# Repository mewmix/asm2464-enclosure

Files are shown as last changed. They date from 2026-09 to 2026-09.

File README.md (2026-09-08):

# ASM2464PD USB4 / M.2 2230 Development Enclosure

Open development project for a compact ASM2464PD + M.2 2230 USB4 enclosure with firmware-development access built into the board and enclosure.

The immediate goals are:

1. reproduce and then improve the public Leaves232 ASM2464PD 2230 reference design;
2. expose the ASM2464PD firmware UART cleanly;
3. provide safe direct SPI access to the external firmware flash for backup, programming, and recovery;
4. co-design the PCB and enclosure rather than treating the enclosure as an afterthought;
5. use an agent-driven KiCad workflow modeled on the public i2cjak Astra + KiStack + T3CAD demonstration;
6. validate as much of the digital/recovery path as possible in simulation before Rev-A hardware.

## Agent-driven workflow

The public i2cjak demonstration describes an Astra-Medium hardware-design loop using **KiStack** and **T3CAD**, a T3Code fork. The exact private prompt/transcript is not published, so this repository documents a reproducible workflow built from the public tools and their documented capabilities.

Start with [`WORKFLOW.md`](WORKFLOW.md). Agents working in this repository must also read [`AGENTS.md`](AGENTS.md) and [`PROJECT_PLAN.md`](PROJECT_PLAN.md).

## Reference design

Electrical/mechanical reference:

- https://github.com/Leaves232/2230-USB4-SSD-Enclosure-Design

Controller datasheet pointer and extracted debug pins:

- [`reference/datasheets/ASM2464PD.md`](reference/datasheets/ASM2464PD.md)

Known reference-board geometry already extracted from the public Gerber/PnP data:

- controller PCB: **22.039834 x 33.680400 mm**;
- ASM2464PD center: **(13.667257, 14.870481) mm** from the PCB lower-left datum;
- USB-C center: **(11.069980, 29.187267) mm**;
- M.2 connector center: **(11.023879, 4.697654) mm**.

## Firmware-development interface

The service interface is deliberately narrow:

- ASM UART TX/RX;
- ASM reset;
- direct external SPI flash CS#/CLK/DI/DO;
- GND and target-voltage sense.

See [`DEBUG_ACCESS_AGENT_INSTRUCTIONS.md`](DEBUG_ACCESS_AGENT_INSTRUCTIONS.md).

## Mechanical model

The current CadQuery fit model lives at:

```text
mechanical/rev-a/model.py
```

Build it with:

```bash
python -m venv .venv
source .venv/bin/activate
pip install -r mechanical/rev-a/requirements.txt
python mechanical/rev-a/model.py
```

Generated STEP/STL files belong under `mechanical/rev-a/build/` and are intentionally ignored until geometry is mature enough to publish as release artifacts.

## Integrated CAD / simulation milestone

The shared board configuration now drives service access, physical SPI-isolation shunts, flash envelope clearance, and the virtual board. The imported upstream CPU executes project-owned reference firmware through UART/SPI MMIO. The CPU regression proves boot, deliberate flash bricking, programmer erase/program/full readback, and recovered boot.

```bash
python -m pip install -r simulation/requirements.txt
# Install SDCC using your platform package manager, then:
python scripts/validate_twin.py
```

See [validation outputs and limits](validation/README.md) and [the shared recovery design](hardware/rev-a/RECOVERY.md). STEP/STL and assembled/exploded PNGs are generated in `mechanical/rev-a/build/`. Geometry includes explicit provisional component envelopes, not a completed routed PCB.

**RTL remains blocked:** no Verilog/RTL sources exist at the inspected authoritative branch tip. `--require-rtl` makes that missing gate fail explicitly. No full dual-backend or fabrication-ready claim is made.

## Design gates before fabrication

Do not release Rev A for fabrication until:

- reference schematic/net tracing is complete;
- UART voltage is established;
- SPI flash voltage and exact part pinout are established;
- ASM SPI bus ownership under reset is proven or explicit isolation is designed;
- ERC/DRC pass with reviewed waivers only;
- USB4/PCIe routing rules are reviewed independently of generic DRC;
- debug connector and mating-cable keepouts are present in the mechanical model;
- ASM thermal path is modeled and does not depend on a printed-plastic lid for sustained operation;
- recovery simulation proves brick -> external flash recovery -> reboot -> UART confirmation.

## Source toolchain

- KiCad / `kicad-cli`
- KiStack: https://github.com/American-Embedded/KiStack
- T3CAD: https://github.com/i2cjak/T3CAD
- CadQuery
- Verilator + cocotb for digital board simulation
- ngspice/Xyce where circuit-level modeling is useful
- LiteNVMe as an optional open NVMe-host reference

## License / reference hygiene

Do not copy third-party source designs or datasheets into this repository unless their license permits redistribution. Keep source pointers, extracted facts, and our own derived design work separated and attributed.

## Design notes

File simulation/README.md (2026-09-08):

# Shared board simulation and imported ASM emulation

The working CPU/CAD milestone uses the **unchanged imported upstream CPU8051**, Memory, and HardwareState implementations at `acc935d351d49c66ab8d1026ee8cb4617609f782`. Generic SDCC-built mcs51 firmware runs from the upstream CODE-loading convention and drives actual UART/SPI MMIO. No CPU or controller RTL has been recreated.

`hardware/rev-a/board.json` couples the mechanical model to flash capacity/profile, boot offset and physical recovery-link states. The virtual programmer and CPU adapter use the same NOR instance. The model supports WEL/WIP, program/erase timing, NOR bit direction, status, ID, interruption and unsafe ownership detection. The firmware emits the expected boot banner; deliberate erasure prevents boot; external reprogramming and full readback restore it.

Run `python scripts/validate_twin.py` after installing SDCC and `simulation/requirements.txt`. See [validation instructions](../validation/README.md) for outputs, exact modeling limits, and the stricter `--require-rtl` gate.

The complete authoritative source tree contains no RTL files. Backend B and CPU/RTL differential comparison are **BLOCKED**, not skipped passes. The preserved two-backend requirements remain in [SIMULATION_WORK_INSTRUCTIONS.md](../SIMULATION_WORK_INSTRUCTIONS.md). Locate the existing RTL in the authoritative project before satisfying that gate.

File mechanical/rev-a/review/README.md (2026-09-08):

# CPU/CAD integration review artifacts

Generated from `model.py` and `hardware/rev-a/board.json` by `scripts/validate_twin.py`. STEP geometry and software renders are retained for this reviewed simulation milestone. `dimensions.json` and `cad-validation.json` record the shared board configuration hash.

The green/blue solids are board envelopes; service, shunt, chip and flash heights remain provisional. The metal insert has a lower locating flange and a modeled thermal pad path to the ASM envelope. This is not a completed PCB assembly or a fabrication release. See `validation/README.md` for unresolved gates.

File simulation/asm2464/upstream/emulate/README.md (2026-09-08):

# ASM2464PD Emulator

8051 CPU emulator for testing and analyzing the ASM2464PD firmware.

## Architecture

```
┌─────────────────────────────────────────────────────────────────┐
│                         Linux Host                               │
│                                                                  │
│  ┌──────────┐     USB      ┌──────────────────────────────────┐ │
│  │ USB App  │◄────────────►│         raw-gadget               │ │
│  │(usb.py)  │  (real USB)  │     (fake USB device)            │ │
│  └──────────┘              └──────────────┬───────────────────┘ │
│                                           │                      │
│                                      MMIO │ registers            │
│                                           ▼                      │
│                            ┌──────────────────────────────────┐ │
│                            │           Emulator               │ │
│                            │  ┌────────────────────────────┐  │ │
│                            │  │      fw.bin (8051)         │  │ │
│                            │  │   - USB interrupt handler  │  │ │
│                            │  │   - Vendor cmd processing  │  │ │
│                            │  │   - State machine          │  │ │
│                            │  └────────────────────────────┘  │ │
│                            │  ┌────────────────────────────┐  │ │
│                            │  │    Hardware Emulation      │  │ │
│                            │  │   - MMIO registers         │  │ │
│                            │  │   - DMA emulation          │  │ │
│                            │  │   - PCIe/NVMe stubs        │  │ │
│                            │  └────────────────────────────┘  │ │
│                            └──────────────────────────────────┘ │
└─────────────────────────────────────────────────────────────────┘
```

## USB Device Passthrough (raw-gadget)

The `usb_device.py` creates a fake USB device using Linux's raw-gadget kernel module.

**CRITICAL: The fake USB device is a passthrough, NOT a handler.**

**NOTE: NEVER implement USB request handling in Python.** The firmware (fw.bin) handles ALL USB requests including GET_DESCRIPTOR, SET_ADDRESS, SET_CONFIGURATION, and vendor commands. The emulator only sets MMIO registers to inject requests; the 8051 firmware code processes them. If USB enumeration doesn't work, fix the MMIO register configuration or investigate firmware flow - do NOT add Python code to handle USB requests directly.

When the host sends USB control messages:

**All USB Control Transfers** (standard and vendor):
1. **raw-gadget receives** the USB setup packet
2. **usb_device.py injects** the request into emulator MMIO registers
3. **Firmware processes** the request via USB interrupt handler (0x0E33)
4. **Firmware writes** response to appropriate registers/buffers
5. **usb_device.py reads** the response from emulator
6. **raw-gadget sends** the response back to the host

### Control Transfer Flow

```
Host                    raw-gadget/usb_device.py              Emulator (fw.bin)
  │                              │                                   │
  │──USB control transfer───────►│                                   │
  │                              │──inject to MMIO registers────────►│
  │                              │  (0x9E00-0x9E07 = setup packet)   │
  │                              │──trigger USB interrupt───────────►│
  │                              │                                   │
  │                              │                    [firmware runs]│
  │                              │                    [reads MMIO]   │
  │                              │                    [processes req]│
  │                              │                    [writes resp]  │
  │                              │                                   │
  │                              │◄──read response from XDATA/MMIO───│
  │◄─────response data──────────│                                   │
```

### USB Descriptor Handling

**Descriptors are handled entirely by firmware through MMIO:**

1. Firmware receives GET_DESCRIPTOR request via setup packet at 0x9E00-0x9E07
2. Firmware reads descriptor data from flash ROM mirror (XDATA 0xE4xx → Code ROM)
   - The hardware maps XDATA reads at 0xE400-0xE500 to code ROM with offset 0xDDFC
   - Formula: `code_addr = xdata_addr - 0xDDFC`
3. Firmware writes response to EP0 FIFO (0xC001)
4. Firmware triggers DMA (writes 0x04 to 0x9092)
5. Hardware DMA copies FIFO data to USB buffer at 0x8000
6. usb_device.py reads response from 0x8000

**IMPORTANT:** The emulator does NOT hardcode descriptor addresses. The `_flash_rom_mirror_read`
callback provides the MMIO hardware behavior - it maps XDATA reads to code ROM. The firmware
determines which addresses to read based on its own descriptor tables.

### Key MMIO Registers

| Register | Purpose |
|---|---|
| 0xC802 | Interrupt status (bit 0 = USB interrupt pending) |
| 0x9000 | USB connection status |
| 0x9101 | USB interrupt flags (bit 5 = vendor command path) |
| 0x9E00-0x9E07 | USB setup packet (8 bytes) |
| 0x910D-0x9112 | CDB data for SCSI/vendor commands |
| 0x90E3 | USB endpoint status |
| 0x8000+  | USB data buffer (for responses) |

### USB Setup Packet Registers (0x9E00-0x9E07)

The firmware handles ALL USB control transfers via these registers:

| Offset | Register | USB Setup Field |
|---|---|---|
| 0x9E00 | bmRequestType | Request type (direction, type, recipient) |
| 0x9E01 | bRequest | Request code (e.g., 0x06 = GET_DESCRIPTOR) |
| 0x9E02 | wValue low | Value field low byte |
| 0x9E03 | wValue high | Value field high byte |
| 0x9E04 | wIndex low | Index field low byte |
| 0x9E05 | wIndex high | Index field high byte |
| 0x9E06 | wLength low | Data length low byte |
| 0x9E07 | wLength high | Data length high byte |

The firmware processes standard USB requests (GET_DESCRIPTOR, SET_ADDRESS, etc.)
as well as vendor-specific requests (E4/E5) through the USB interrupt handler at 0x0E33.

### Vendor Commands (E4/E5)

Vendor commands follow the same passthrough model:

1. Host sends UAS command packet on EP4 OUT
2. raw-gadget receives bulk transfer
3. usb_device.py injects CDB into registers 0x910D+
4. Firmware processes via vendor handler (0x5333 → 0x4583)
5. For E4 reads: firmware DMAs data to 0x8000
6. usb_device.py reads response buffer
7. raw-gadget sends data back on EP1 IN

## Files

- `emu.py` - Main Emulator class
- `cpu.py` - 8051 CPU emulation
- `memory.py` - Memory system (code, xdata, idata, sfr)
- `hardware.py` - MMIO register emulation
- `raw_gadget.py` - Python wrapper for raw-gadget kernel module
- `usb_device.py` - USB device passthrough (connects raw-gadget to emulator)

## Running Tests

```bash
# Test firmware handling (without real USB)
pytest test/test_emulator.py -v

# Test with real USB device (requires root, raw-gadget module)
sudo modprobe dummy_hcd raw_gadget
sudo python emulate/emu.py --usb-device fw.bin
```

## Requirements for USB Device Mode

1. Linux kernel with dummy_hcd and raw_gadget modules
2. Root privileges
3. No conflicting gadget drivers

```bash
# Load required modules
sudo modprobe dummy_hcd
sudo modprobe raw_gadget

# Verify
ls /dev/raw-gadget
ls /sys/class/udc/
```

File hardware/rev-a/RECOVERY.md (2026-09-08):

# Proposed Rev-A recovery architecture

`board.json` is the shared digital/mechanical contract. The current design selects **four removable shunts**, one each in CS#, CLK, MOSI, and MISO. The programmer connects to the flash side. Reset is held during shunt removal and replacement. All four links must be open before programmer attachment. VREF is sense-only; the programmer must not power the target through it.

The CAD includes separate service-connector and isolation-shunt envelopes and top service openings. These are **design envelopes**, not verified manufacturer models. The isolated flash needs a defined idle CS# level in the eventual schematic; resistor value, rail voltage, connector part and signal integrity remain electrical gates. No completed Rev-A schematic/routed PCB is claimed by this fit-model milestone.

Simulation ownership is derived from each physical link state. Reset alone never grants ownership. A deliberately shorted link produces a contention error. A controller that refuses to tri-state cannot drive through removed shunts.

Procedure: hold reset → remove all four shunts → attach programmer to flash-side connector → read JEDEC → save complete backup → erase/program → full readback and SHA-256 verification → detach programmer → replace all four shunts → release reset → capture UART boot.

Controller SPI signal names in the previous reference notes contain conflicting DI/DO direction descriptions. This model therefore uses functional MOSI/MISO names and does **not** assign new ASM ball-to-flash wiring. Resolve the actual net directions from the reference schematic before authoring the board. The CAD and simulator share ownership architecture, not an unverified netlist.

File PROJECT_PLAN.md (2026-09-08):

# USB4 2230 ASM2464PD Development Enclosure — Repo Plan

## Project goal

Build our own compact ASM2464PD + M.2 2230 USB4 enclosure that is also usable as a firmware-development unit.

The development scope is deliberately narrow:

1. **Write/read the ASM2464PD external firmware flash directly over SPI.**
2. **Debug/controller-console access over UART.**

Do not add JTAG, SWD, I2C, general GPIO, or unrelated service interfaces unless a later requirement explicitly needs them.

## Mandatory coupled simulation deliverable

Rev-A consists of the KiCad board, CadQuery mechanical/thermal enclosure, imported/pinned existing ASM CPU-emulator + Verilog backends, and a common board model proving firmware boot, UART, external SPI programming, deliberate bricking, and recovery. Check changes across all four layers. Follow [`SIMULATION_WORK_INSTRUCTIONS.md`](SIMULATION_WORK_INSTRUCTIONS.md), sections 13–25, in full.

The first simulation milestone is deterministic project-owned reference firmware boot and brick/recovery against both imported backends using the same board and fault corpus. Both must ultimately pass; unsupported execution is a recorded blocker. More realistic firmware follows without changing the board underneath it. Physical validation below remains required.

## Primary references

### ASM2464PD datasheet

See [`reference/datasheets/ASM2464PD.md`](reference/datasheets/ASM2464PD.md).

Relevant controller pins currently extracted from the datasheet:

- `UART_TX` — B21
- `UART_RX` — A21
- `SPI_CS#` — A2
- `SPI_DO` — A3
- `SPI_DI` — A4
- `SPI_CLK` — A5
- `RST#` — H1

### Reference PCB

Use Leaves232's `2230-USB4-SSD-Enclosure-Design` as the electrical/mechanical reference baseline. Keep imported/reference material read-only and place our changes under our own `hardware/` and `mechanical/` trees.

Known reference-board facts already extracted:

- controller PCB: 22.039834 x 33.680400 mm;
- controller: ASM2464PD;
- external serial flash: U31, `ZD25WQ16CEIGR`;
- M.2 2230 SSD extends beyond the controller PCB;
- USB-C receptacle is at the controller-board end.

## Repository structure target

```text
reference/
  datasheets/
    ASM2464PD.md
  leaves232-b2/
    README.md
    debug-net-map.md
hardware/
  rev-a/
    schematic/
    pcb/
    fab/
mechanical/
  rev-a/
    model.py
    build/
validation/
  electrical/
  mechanical/
docs/
  uart-debug.md
  flash-programming.md
README.md
PROJECT_PLAN.md
```

## Rev A debug connector

Prefer a compact keyed 2x5, 1.27 mm header or an equivalent pogo/Tag-Connect footprint if enclosure constraints make a permanent header undesirable.

Provisional signals:

| Pin | Signal | Direction/role |
|---:|---|---|
| 1 | GND | reference |
| 2 | VREF_SENSE | target logic/flash-rail sense only |
| 3 | ASM_UART_TX | target -> adapter |
| 4 | ASM_UART_RX | adapter -> target |
| 5 | ASM_RST_N | controller reset control |
| 6 | ASM_SPI_CS_N | flash programming |
| 7 | ASM_SPI_CLK | flash programming |
| 8 | ASM_SPI_DI | programmer MOSI -> flash path |
| 9 | ASM_SPI_DO | flash -> programmer MISO path |
| 10 | GND | reference |

Do **not** provide debugger/programmer power to the board through `VREF_SENSE`.

## Electrical architecture

### UART

Route the dedicated ASM2464PD UART pins directly to the development connector through optional small series resistors/0-ohm links for bring-up flexibility.

Requirements:

- determine and document the UART I/O voltage before attaching an adapter;
- label TX/RX from the **target's perspective**;
- keep the traces short and away from USB4 high-speed pairs;
- provide a solid ground next to the UART pins.

The repo must not hard-code a UART baud rate unless it is confirmed from firmware/runtime evidence. Datasheet pin identity and runtime serial configuration are separate facts.

### Direct SPI flash programming

U31 is the firmware flash. The direct-programming path must reach the **flash-side** SPI nets:

- CS#
- CLK
- DI/MOSI
- DO/MISO
- target ground
- target flash-rail reference/sense

The normal operating path remains ASM2464PD <-> U31.

The key design problem is **bus ownership**. An external programmer must never fight the ASM2464PD for the flash bus.

Implementation order:

1. Prove whether asserting `ASM_RST_N` causes the controller to release/tri-state all four SPI signals.
2. If yes, document `RST# asserted + board powered normally` as the preferred in-circuit programming state.
3. If no, add a deliberate hardware isolation mechanism in Rev A. Prefer a low-risk topology that does not compromise normal flash timing/signal integrity. Do not rely on software cooperation from potentially corrupted firmware.

Avoid casually inserting analog switches or long stubs into the production flash bus. If active isolation is needed, it requires signal-integrity review and validation at the actual flash clock rate.

## Bring-up workflow target

### UART firmware debug

1. Power the enclosure normally over USB-C.
2. Connect GND and `VREF_SENSE` first.
3. Confirm logic voltage.
4. Connect adapter RX to `ASM_UART_TX` and adapter TX to `ASM_UART_RX`.
5. Capture boot/debug output.
6. Determine baud/framing from verified firmware/runtime evidence and record it in `docs/uart-debug.md`.

### Direct flash write/recovery

1. Power the target using the documented target-power method.
2. Assert the verified controller-reset/isolation state.
3. Confirm the ASM is not driving CS#/CLK/DI/DO.
4. Connect programmer GND and sense the target flash voltage.
5. Read flash JEDEC ID.
6. Read and save a complete backup before any write/erase.
7. Program only a verified image with size/range checks.
8. Read back and verify the programmed contents.
9. Disconnect programmer.
10. Release reset/isolation and boot normally.

## Mechanical requirements

The enclosure model must include:

- the real debug-connector body;
- mating-plug/cable keepout;
- service aperture or removable cover;
- no collision with the USB-C cable;
- no interference with the M.2 2230 SSD;
- no loss of thermal contact to the ASM2464PD heat spreader/pad.

The header must be usable with the device fully assembled.

## Validation gates

Rev A is not complete until all of these are demonstrated:

- UART TX/RX continuity from ASM balls to connector;
- UART voltage confirmed;
- SPI CS#/CLK/DI/DO continuity from U31/ASM bus to connector;
- flash voltage confirmed;
- reset/isolation behavior proven with a scope or logic analyzer;
- external programmer can read JEDEC ID without contention;
- full flash can be backed up and verified;
- a test image can be written/read-back verified on sacrificial hardware;
- UART can capture controller boot/debug output;
- enclosure/cable/header clearances pass mechanically;
- ASM thermal-interface geometry remains intact.

## Deliverable sequence

1. `reference: add ASM2464PD datasheet facts and source pointer`
2. `reference: trace B2 UART and external-flash nets`
3. `hardware: add Rev A UART + direct-SPI service connector`
4. `hardware: add reset/isolation strategy for safe flash programming`
5. `mechanical: model debug connector and service aperture`
6. `docs: add UART debug and flash recovery procedures`
7. `validation: prove bus release, flash read/write, UART capture, and enclosure clearance`

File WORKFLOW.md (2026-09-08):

# Agent-Driven Hardware Workflow

## What this reproduces from the public demo

The public i2cjak post says Astra-Medium produced a Bluetooth hardware design in roughly 30 minutes using **KiStack** and **T3CAD**, i2cjak's fork of T3Code. Public T3CAD documentation describes an agent-driven workspace combining coding-agent conversations with KiCad schematic, PCB, Gerber, BOM, footprint, symbol, 3D, and analysis views. KiStack is a human-written set of agent skills for KiCad schematic work, PCB review, parts/BOM decisions, exports, and Gerber review.

The original private agent transcript is not public. This document therefore defines our reproducible equivalent for the ASM2464PD enclosure.

## 0. Install the toolchain

### KiCad

Install a current KiCad release and ensure `kicad-cli` is on PATH. T3CAD requires `kicad-cli` for BOM, footprint, symbol, and 3D previews. Python 3 is required for Gerber previews.

Verify:

```bash
kicad-cli version
python3 --version
```

### KiStack

Install the public KiStack skills:

```bash
npx skills add American-Embedded/kistack
```

Source: https://github.com/American-Embedded/KiStack

### T3CAD

T3CAD currently runs from source. Install Vite+ first.

macOS/Linux:

```bash
curl -fsSL https://vite.plus | bash
```

Windows PowerShell:

```powershell
irm https://vite.plus/ps1 | iex
```

Then:

```bash
git clone https://github.com/i2cjak/T3CAD.git
cd T3CAD
vp i
vp run dev
```

Open the pairing URL printed by the development server. `vp run dev --share` can expose the isolated development environment over a Tailnet.

### Mechanical CAD

The tweet's stack is electronics-focused. This repository adds CadQuery for deterministic, version-controlled enclosure geometry:

```bash
pip install -r mechanical/rev-a/requirements.txt
```

## 1. Start the agent in repository mode

The agent must work against this repository, not a blank chat.

First read, in order:

1. `AGENTS.md`
2. `PROJECT_PLAN.md`
3. `DEBUG_ACCESS_AGENT_INSTRUCTIONS.md`
4. `reference/datasheets/ASM2464PD.md`
5. the Leaves232 reference repo and its schematic/PCB/fabrication files

The first response should summarize hard facts, assumptions, unresolved electrical questions, and the next smallest design pass. Do not immediately generate a finished PCB.

## 2. Ingest the reference design as evidence

Use the Leaves232 project as a read-only baseline:

- schematic and PCB source;
- Gerbers and drill files;
- BOM;
- pick-and-place;
- board outline;
- component placement;
- power tree;
- USB-C / ASM2464PD / M.2 topology;
- external flash connection;
- thermal constraints.

Create project-owned evidence artifacts rather than modifying the reference:

```text
reference/leaves232-b2/
  debug-net-map.md
  debug-net-map.json
  power-tree.md
  placement-datums.json
  open-questions.md
```

Every assertion should be classified as one of:

- `DATASHEET`
- `REFERENCE_SCHEMATIC`
- `REFERENCE_PCB`
- `FAB_OUTPUT`
- `MEASURED`
- `INFERRED`
- `ASSUMED`

## 3. Freeze the design contract before placement

Create/maintain a short design contract containing:

- exact board outline target;
- M.2 2230 mechanical datum;
- USB-C receptacle and shell datum;
- ASM2464PD footprint and thermal region;
- external SPI flash part/footprint;
- power requirements;
- UART/SPI recovery connector choice;
- enclosure/service-access constraints;
- manufacturing stackup and routing constraints.

Do not let the agent silently change these during routing.

## 4. Schematic pass

Use the agent + KiStack to reconstruct/author the KiCad schematic in small subsystems:

1. USB-C input and protection;
2. ASM2464PD core/power/clock/reset;
3. external SPI firmware flash;
4. UART + SPI recovery/service connector;
5. PCIe/M.2 interface;
6. power regulators and sequencing;
7. status LED and remaining support circuits.

After each subsystem:

```bash
kicad-cli sch erc <project>.kicad_sch
```

Review warnings deliberately. Do not suppress ERC failures merely to get a green build.

## 5. Footprint lock

Before serious PCB placement, lock footprints whose physical geometry affects the enclosure:

- USB-C receptacle;
- ASM2464PD;
- M.2 connector;
- SPI flash;
- large capacitors/inductors;
- service/debug connector;
- mounting/retention hardware.

Confirm courtyard, body height, pin-1 orientation, and 3D model where available.

This is a critical correction to a pure "one-shot" flow: an electrically valid connector that cannot be assembled or accessed is still a failed design.

## 6. PCB placement loop in T3CAD

Use T3CAD as the steering surface while the agent edits the KiCad project.

Recommended loop:

1. agent proposes one placement/routing pass;
2. inspect schematic/PCB/3D in T3CAD;
3. compare against the frozen mechanical datums;
4. run DRC;
5. inspect high-speed routes manually;
6. commit a small checkpoint;
7. continue.

Prioritize placement in this order:

1. board outline / USB-C / M.2 mechanical endpoints;
2. ASM2464PD;
3. clocks and high-speed support parts;
4. power conversion/decoupling;
5. SPI flash close to ASM;
6. recovery connector where it remains accessible in the final enclosure;
7. remaining low-speed support circuitry.

## 7. High-speed routing rules

Do not treat generic autorouting or a clean DRC as proof of USB4/PCIe correctness.

The agent must explicitly track:

- stackup and target differential impedance;
- pair geometry and reference plane continuity;
- intra-pair and inter-pair skew budgets where applicable;
- via count and stubs;
- return-path discontinuities;
- connector escape geometry;
- separation from switch-node/power noise;
- avoidance of unnecessary debug/test stubs on high-speed nets.

Reference-design topology is evidence, not permission to copy blindly.

## 8. Firmware-development access

Implement only what we need:

- `ASM_UART_TX`
- `ASM_UART_RX`
- `ASM_RST_N`
- `ASM_SPI_CS_N`
- `ASM_SPI_CLK`
- `ASM_SPI_DI`
- `ASM_SPI_DO`
- GND
- target-voltage sense

Direct flash programming must be safe even when firmware is corrupt. Bus ownership is a hardware requirement. Prove that reset tri-states the ASM SPI pins, or provide explicit isolation.

See `DEBUG_ACCESS_AGENT_INSTRUCTIONS.md`.

## 9. Mechanical co-design

After the first stable placement pass, regenerate the CadQuery enclosure from actual PCB datums rather than hand-entered estimates.

Mechanical iteration must check:

- board outline;
- USB-C opening and plug insertion envelope;
- SSD envelope;
- component maximum-Z envelopes;
- debug connector body and mating cable;
- thermal pad/spreader compression;
- screw/clip locations;
- assembly sequence;
- service access without opening the enclosure.

Run PCB and enclosure development in parallel from this point onward.

## 10. Simulation before fabrication

The four coupled Rev-A artifacts and mandatory simulation requirements are defined in [`SIMULATION_WORK_INSTRUCTIONS.md`](SIMULATION_WORK_INSTRUCTIONS.md), sections 13–25. Read and follow that contract in full. Reuse pinned imports of the existing CPU emulator and Verilog model from `mewmix/asm2464pd-opal`; do not build replacement ASM implementations.

The first milestone is deterministic generic firmware boot and deliberate brick/recovery using both execution backends on the same virtual board. Both must ultimately pass. Unsupported capabilities are recorded blockers, never passing mocks. The flash, UART, reset, programmer ownership, fault corpus, and synthetic PCIe/NVMe endpoint belong to the common board model. Recovery must represent the circuit actually selected for the PCB.

Keep existing circuit-level/electrical checks and physical validation gates. LiteNVMe remains an optional secondary oracle subordinate to stock ASM evidence.

## 11. Automated validation loop

Each meaningful design pass should run as much of this as applies:

```text
schematic ERC
PCB DRC
BOM generation/review
footprint review
Gerber export/review
pick-and-place export/review
3D inspection
mechanical model build
clearance/interference checks
simulation regression
```

The point of KiStack/T3CAD is not "AI drew a PCB." The useful loop is **agent edit -> deterministic validation -> visual inspection -> evidence update -> next agent edit**.

## 12. Pre-fabrication signoff

Before ordering Rev A, require all of the following:

- schematic reviewed subsystem-by-subsystem;
- DRC/ERC clean or every waiver documented;
- high-speed routing independently reviewed;
- pin-1/orientation review complete;
- BOM availability checked;
- flash/UART voltage assumptions resolved;
- safe external-flash ownership strategy resolved;
- fabrication outputs reviewed, not merely generated;
- enclosure interference check passes;
- thermal strategy defined;
- brick/recovery simulation passes;
- manufacturing notes and bring-up procedure committed.

## Physical fabrication, assembly, and feedback

On physical Rev A:

1. inspect bare/assembled board;
2. validate rails before fitting the ASM/SSD where practical;
3. measure reset and flash-bus behavior;
4. back up factory/reference flash before writing;
5. validate UART electrically;
6. perform controlled SPI recovery test on sacrificial/rework-safe hardware;
7. exercise USB4/NVMe and thermal behavior;
8. feed measured dimensions, temperatures, signal captures, and failures back into the repo as `MEASURED` evidence.

The physical board is the final oracle for the next revision.

## Canonical agent prompt

Use this as the starting instruction for an Astra/Work/Codex-style agent:

> The Rev-A deliverable consists of FOUR coupled artifacts: (1) KiCad ASM2464PD development board; (2) CadQuery mechanical/thermal enclosure; (3) imported/pinned ASM2464 CPU-emulator + Verilog simulation backend; (4) board-level simulation proving firmware boot, UART debugging, external SPI programming, deliberate bricking, and recovery. Check changes in each layer against the other layers. Reuse the existing ASM emulator/RTL; never replace it with a toy ASM behavioral stub. Work directly in `mewmix/asm2464-enclosure`. Read `AGENTS.md`, `WORKFLOW.md`, `PROJECT_PLAN.md`, `DEBUG_ACCESS_AGENT_INSTRUCTIONS.md`, `SIMULATION_WORK_INSTRUCTIONS.md` (all mandatory sections 13–25), and the ASM2464PD datasheet notes before editing anything. Treat the Leaves232 ASM2464PD 2230 project as a read-only reference baseline. Reconstruct evidence first, then make the smallest reviewable design change. Use KiStack for KiCad-specific validation and T3CAD as the visual steering/inspection workspace. After every schematic or PCB pass run the available ERC/DRC/export checks and record unresolved assumptions. Preserve high-speed topology and mechanical datums deliberately. Our required service access is only UART debug plus safe direct SPI firmware-flash recovery. Do not claim a design is fabrication-ready until electrical, mechanical, thermal, recovery-simulation, and manufacturing-output gates in `WORKFLOW.md` pass. Commit small, auditable changes with evidence and validation notes.

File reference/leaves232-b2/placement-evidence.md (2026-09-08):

# Reference placement evidence

Source: https://github.com/Leaves232/2230-USB4-SSD-Enclosure-Design
Commit: `8b7a5b2e510b9e8b6a98e5ba4e491064da3b950c`.
Read-only inputs: Pick Place for ASM2464PD - B2 Sample.csv and B2 Sample.GKO.

U31 row: `ZD25WQ16CEIGR`, BottomLayer, `USON-8_L3.0-W2.0-P0.50-BL-EP`, center 1394.313 / 1157.313 mil, rotation 0.
Gerber lower-left datum: X57029 / Y35900 in 2.5-inch coordinates = 570.29 / 359 mil.
Subtract datum, then multiply mil by 0.0254 to obtain mm. This agrees with the existing ASM U2 center from its 1108.371 / 944.452-mil PnP coordinates.

U31 footprint label supplies a nominal 3-by-2-mm body envelope, but the model's XY orientation and 0.6-mm height remain assumptions pending footprint/package validation. Geometry does not establish SPI net direction or supply voltage.

No third-party manufacturing files or firmware images are redistributed here.

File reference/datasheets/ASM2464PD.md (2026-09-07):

# ASM2464PD Datasheet Reference

Authoritative device reference for the controller used by this project.

## Public datasheet copy

- **ASM2464PD Data Sheet, R0.2**
- Public mirror: https://egpu.io/wp-content/uploads/wpforo/attachments/160145/15128-ASM2464PDData-SheetR02-2.pdf

Do not vendor or redistribute the PDF unless its redistribution rights are confirmed. Keep this repository entry as a source pointer plus project-specific extracted facts.

## Firmware-development signals used by this project

| Function | ASM2464PD ball/pin | Project net name | Purpose |
|---|---|---|---|
| UART TX | B21 | `ASM_UART_TX` | Controller debug/console output |
| UART RX | A21 | `ASM_UART_RX` | Controller debug/console input |
| SPI chip select | A2 | `ASM_SPI_CS_N` | External firmware-flash select |
| SPI data out | A3 | `ASM_SPI_DO` | ASM -> flash / programmer MISO-side observation |
| SPI data in | A4 | `ASM_SPI_DI` | Flash/programmer -> ASM MOSI-side input |
| SPI clock | A5 | `ASM_SPI_CLK` | External firmware-flash clock |
| Reset | H1 | `ASM_RST_N` | Hold/reset controller during recovery/programming if electrically valid |

The datasheet exposes a **4-wire SPI interface** for the external firmware flash. This repo should not describe the ASM2464PD side as QSPI unless later evidence proves additional controller flash-I/O pins exist.

## Design rule

These extracted pin assignments are permitted as schematic/PCB requirements, but voltage levels, reset-time pin states, and in-circuit programming behavior must still be verified electrically before manufacturing. In particular, `ASM_RST_N` must not be assumed to release/tri-state the SPI bus until that behavior is demonstrated.

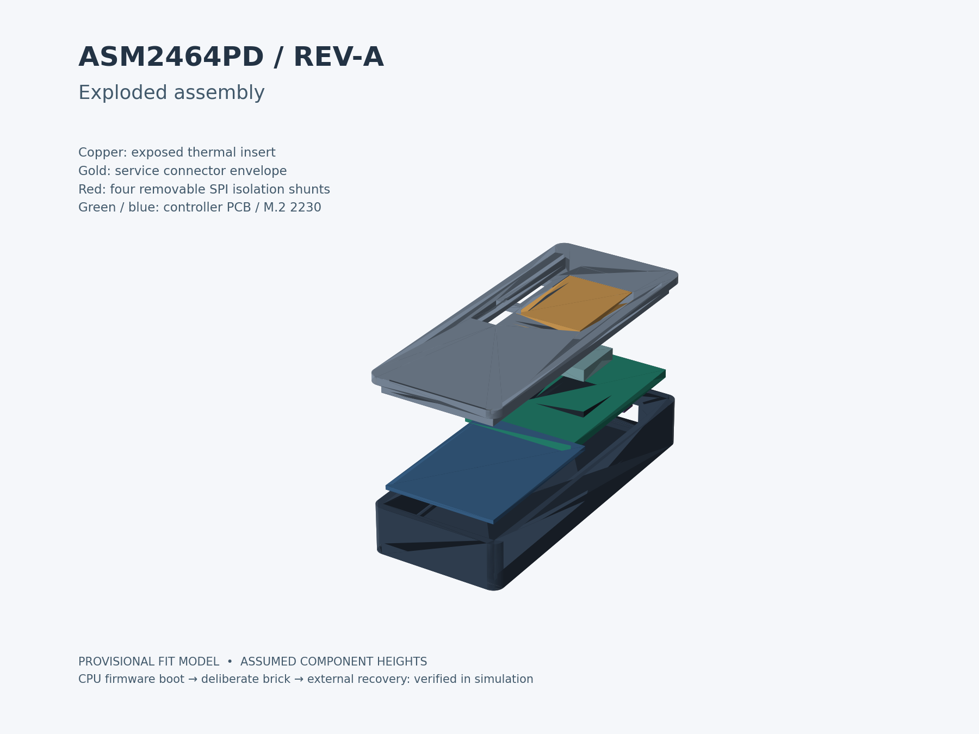
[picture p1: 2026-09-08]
mechanical/rev-a/review/exploded.png

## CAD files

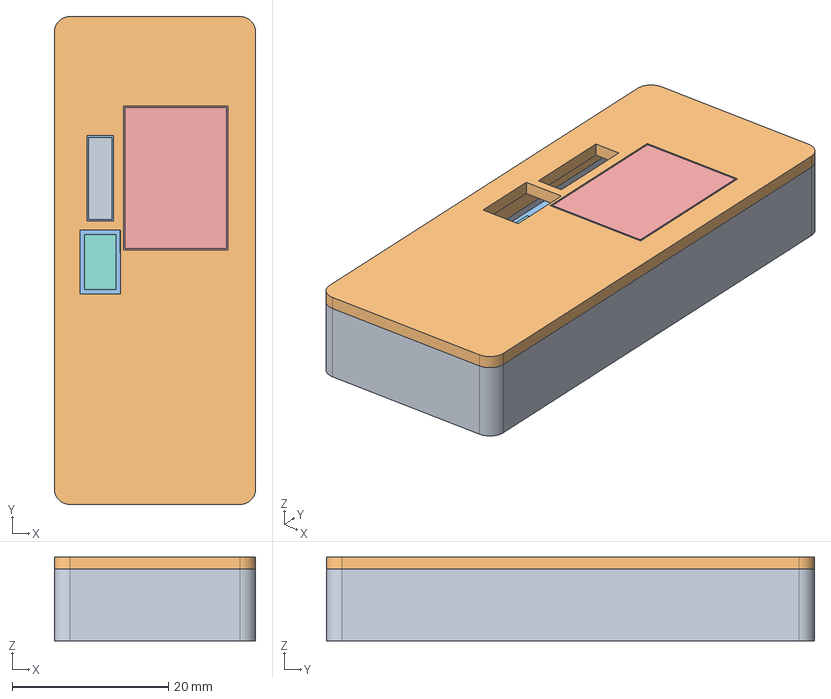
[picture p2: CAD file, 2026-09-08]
mechanical/rev-a/review/assembly.step
25.7 x 62.4 x 10.7 mm

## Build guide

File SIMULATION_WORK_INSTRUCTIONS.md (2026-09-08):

# Mandatory ASM2464 Rev-A Co-Simulation Work Instructions

The Rev-A deliverable consists of FOUR coupled artifacts:

1. KiCad ASM2464PD development board.
2. CadQuery mechanical/thermal enclosure.
3. Imported/pinned ASM2464 CPU-emulator + Verilog simulation backend.
4. Board-level simulation proving firmware boot, UART debugging, external SPI programming, deliberate bricking, and recovery.

A change to one layer must be checked against the other layers. The existing ASM emulator/RTL is an engineering asset and MUST be reused. Do not replace it with a toy ASM behavioral stub. These requirements are mandatory parts of the Work assignment.

## 13. Import the existing ASM2464 emulation stack

Do NOT create a new ASM CPU emulator or controller RTL from scratch.

The authoritative source is `mewmix/asm2464pd-opal`, branch `agent/full-firmware-lifecycle`. At the beginning of implementation inspect the LIVE branch tip and discover the actual paths for the existing CPU emulator, Verilog/RTL models, peripheral models, test harnesses, memory maps, firmware-loading code, and relevant lifecycle tests. Do not guess paths from this document.

The last supplied baseline was `7d7fb9fdf8ecfbbd8cd4eb54a17f1cf8e416f90c`. During this instruction update, the live GitHub branch ref resolved to `acc935d351d49c66ab8d1026ee8cb4617609f782` on 2026-09-07. This observation is NOT an imported or validated snapshot. VERIFY the live tip again before importing, then pin the exact resolved commit for the whole import.

The source branch remains authoritative for ASM firmware/CPU reconstruction. The enclosure consumes a pinned copy of the portions needed for hardware co-simulation; do NOT move firmware-reconstruction ownership here.

## 14. Import / provenance policy

Vendor a reproducible snapshot under this layout:

```text
simulation/
  asm2464/
    upstream/
      ORIGIN.md
      <pinned imported emulator/RTL sources>
    adapter/
      spi/
      uart/
      reset/
      pcie_nvme/
    firmware/
      reference/
  flash/
  programmer/
  board/
  tests/
  traces/
```

Keep `upstream/` as close to the source as possible. Do not casually edit imported code; project-specific behavior belongs in adapters.

Create `simulation/asm2464/upstream/ORIGIN.md` recording source repository, source branch, source commit SHA, import date, exact imported paths, omitted dependencies, unavoidable local patches, and license/provenance notes.

Create a deterministic `scripts/import_asm2464_sim.py` or `.sh` that reproduces the snapshot from the recorded commit. Record dependency versions and any patch application needed for reproduction. Prefer a pinned vendored snapshot over a moving branch at runtime. Inspect redistribution rights before importing dependencies or firmware.

## 15. Two ASM execution backends

Where the existing project permits it, expose:

- Backend A: the existing software CPU emulator.
- Backend B: the existing Verilog/RTL model.

Both connect through a common board-facing pin/MMIO adapter to ONE board model covering external flash, UART, reset, power state, and PCIe/NVMe. Both consume the SAME flash contents, reset sequence, UART expectations, external-programmer behavior, fault injections, and test vectors. Normalize externally visible behavior for comparison. Do not let backend-specific board models diverge.

If source capabilities block either backend, record the precise unsupported behavior and evidence. Unsupported execution is a blocker, not a passing substitute or permission to invent a replacement ASM.

## 16. Generic reference firmware

Create small project-owned deterministic reference firmware specifically for simulation. Do NOT put proprietary ASMedia production firmware in this public repository without explicit redistribution rights.

Use the actual architecture, memory map, build format, reset vector, linker requirements, and image-loading convention established by the authoritative emulator work. Do not invent these before source inspection.

The first firmware initializes minimum runtime state and UART, emits a deterministic boot banner, exercises external-flash access where the architecture/model permits, reports status, and enters idle/heartbeat. Keep exact strings machine-testable, for example:

```text
ASM2464 REF FW
BUILD=<build-id>
FLASH_ID=<jedec-id>
FLASH_STATUS=<status>
BOOT=OK
```

Produce an ELF where applicable, raw binary, flash image, map file, symbol file, SHA-256, and build manifest. Suggested output directory: `simulation/asm2464/firmware/reference/build/`, including `asm2464_ref.elf`, `asm2464_ref.bin`, `asm2464_ref.map`, `asm2464_ref.sym`, `flash.bin`, `SHA256SUMS`, and `manifest.json`.

The manifest records source commit, compiler/toolchain, exact build command, firmware and flash-image SHA-256, load address/layout, and expected UART banner. Distinguish the enclosure firmware source commit from the imported emulator commit. Make builds deterministic where practical, including a stable build ID. Document inapplicable output formats rather than fabricating them.

## 17. Common board model

Build the virtual board around the imported ASM implementation rather than mocking away the ASM. Required connections:

| ASM / board interface | Connected model |
|---|---|
| ASM SPI pins | Behavioral ZD25WQ16-style external firmware flash |
| ASM UART | Virtual UART terminal/assertion harness |
| ASM reset | Board reset and recovery-state model |
| External SPI recovery connector | Virtual programmer accessing the SAME physical flash model |
| ASM PCIe/NVMe side | Synthetic downstream endpoint |
| Optional differential reference | LiteNVMe |

The board model must be independent of the selected execution backend.

## 18. Flash must act like hardware

Do not expose firmware storage as unrestricted RAM. Model JEDEC identification, READ, WREN, WRDI, WEL, WIP, status registers, page program, sector erase, block/chip erase where applicable, page and erase boundaries, program/erase timing, power-up state, reset behavior, and illegal operations.

Enforce NOR semantics: program changes only physically permitted bits, erase restores erased state, and programming cannot silently perform arbitrary RAM writes. Support deliberate interruption during page program, sector erase, flash read, and reset transitions. Derive part-specific commands, geometry, and timing from evidence; label unsupported/assumed interruption outcomes.

## 19. CPU emulator vs Verilog differential test

Run the SAME firmware and SAME board corpus against both backends whenever technically possible. Capture normalized events:

```text
RESET_ASSERT RESET_RELEASE
SPI_CS_ASSERT SPI_TX SPI_RX SPI_CS_RELEASE
FLASH_READ FLASH_WREN FLASH_PROGRAM FLASH_ERASE FLASH_STATUS
UART_TX
MMIO_READ MMIO_WRITE
PCIE_CFG_READ PCIE_CFG_WRITE
NVME_MMIO_READ NVME_MMIO_WRITE
```

Classify comparisons as exact match, semantically equivalent, timing-only difference, CPU-emulator discrepancy, RTL discrepancy, or unknown/unmodeled behavior. Preserve raw and normalized traces and document normalization rules. Do not assign fault to a backend without supporting evidence; otherwise classify it as unknown.

Functional equivalence is the first target. Do not require cycle-exact equality unless source evidence supports it.

## 20. Basic reference-firmware regression

Build generic firmware, construct the flash image, load identical images into the common flash model for each run, reset the CPU-emulator backend, require expected UART banner/status, repeat with Verilog, and compare normalized traces.

PASS requires both backends to execute the image, reach expected boot state, emit semantically matching UART output, make valid external-flash accesses, and avoid unexpected bus contention. Record every difference. A skipped/unsupported backend cannot satisfy this two-backend gate.

## 21. Full brick / recovery regression

Run the following on the CPU emulator first, then the same regression on Verilog where supported. Ultimately both must pass:

1. Build known-good generic firmware and program virtual flash.
2. Boot with the imported ASM implementation; require UART `BOOT=OK`.
3. Destroy/corrupt the boot image, reset, and require normal boot to fail.
4. Assert the hardware recovery condition; ASM relinquishes the flash bus OR modeled physical isolation disconnects it.
5. Attach the virtual external programmer.
6. Read JEDEC ID and existing flash contents.
7. Erase and program the known-good image.
8. Perform full readback verification and require SHA-256 match.
9. Disconnect the programmer and return flash-bus ownership to ASM.
10. Reset ASM and require reference firmware boot with UART `BOOT=OK`.

Ensure corrupt-image failure is observed from actual execution and that recovery uses programmer transactions through the shared flash model. Never fake UART success or repair flash by bypassing hardware semantics.

## 22. Hardware recovery architecture must match PCB

Model the actual recovery circuit selected for the Rev-A schematic. Do not create a magical simulation-only ownership signal. If Rev-A uses reset-held tri-state, 0-ohm isolation, series resistors, bus/analog switch, buffer, or jumper, represent that mechanism and its actual ownership limits.

The PCB schematic, simulation, and recovery procedure must describe the SAME architecture. Reset alone is not evidence of tri-state; series resistors alone do not establish disconnection. Keep unproven recovery configurations explicitly provisional. Direct recovery must not require healthy firmware. Simulation does not replace physical scope/logic-analyzer ownership validation.

## 23. Fault-injection matrix

Run both backends, where supported, against every case below:

- blank flash;
- corrupt reset/boot region;
- single-bit corruption;
- invalid firmware hash;
- bad JEDEC ID;
- flash stuck BUSY;
- WREN ignored;
- WEL unexpectedly cleared;
- program interrupted;
- erase interrupted;
- reset during flash access;
- reset during boot;
- brownout;
- rapid reset;
- programmer attached too early;
- programmer detached too late;
- ASM refuses to relinquish SPI;
- ASM/programmer contention.

Track CPU-emulator result, Verilog result, expected hardware behavior, and confidence/evidence source for each row. Retain failures and unsupported cases. Do not invent firmware hash enforcement if the established boot path lacks it; report that limitation explicitly.

## 24. Connection to the existing firmware project

Do not duplicate lifecycle reverse-engineering already completed in `mewmix/asm2464pd-opal`.

| Authoritative project | Responsibilities |
|---|---|
| `asm2464pd-opal` | ASM CPU behavior, reconstructed firmware behavior, controller MMIO, firmware lifecycle, PCIe/NVMe reconstruction, firmware-facing tests |
| `asm2464-enclosure` | Physical PCB, power/reset circuitry, external flash, UART connection, programmer ownership, mechanical enclosure, thermal path, board digital twin, electrical simulation, ASM integration with modeled hardware |

Document likely emulator/firmware-model defects exposed by enclosure simulation and fix them in the authoritative project where appropriate. Do not permanently fork that behavior inside enclosure adapters.

## 25. LiteNVMe role

LiteNVMe remains an optional SECONDARY differential oracle. Compare ASM behavior and LiteNVMe reference behavior through the synthetic downstream PCIe/NVMe target, connected to the board and imported CPU/RTL implementations grounded in ASM firmware reconstruction and stock evidence.

LiteNVMe must never redefine observed ASM behavior. Use it to identify likely protocol bugs, missing initialization, queue setup mistakes, invalid MMIO ordering, reset/recovery problems, and DMA mistakes.

Evidence priority:

1. Physical/stock ASM evidence.
2. ASM datasheet/reference evidence.
3. Protocol requirements.
4. LiteNVMe reference behavior.

## First milestone and validation statement

First prove generic firmware boot and brick/recovery through both imported execution backends on the same virtual Rev-A board, with UART, SPI, reset, ZD25WQ16-style flash, and programmer connections. Then introduce progressively more realistic firmware images without replacing the board model.

Report: “Rev-A simulation was validated against asm2464pd-opal emulator commit <full SHA>” only after the corresponding tests actually pass. Record enclosure commit, firmware/image hashes, backend/tool versions, commands, traces, and limitations with that result. Instruction changes alone do not establish imported backends, firmware execution, passing regression, or fabrication readiness.

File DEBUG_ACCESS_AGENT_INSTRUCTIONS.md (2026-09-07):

# ASM2464PD Firmware Development Access — Agent Instructions

## Objective

Extend the USB4 2230 project only enough to support two development operations:

1. **direct read/write/recovery of the ASM2464PD external firmware flash over SPI**;
2. **ASM2464PD firmware debug/console over UART**.

Do not add JTAG, SWD, I2C, generic GPIO, or other debug buses unless later evidence shows they are required for one of those two operations.

Read [`PROJECT_PLAN.md`](PROJECT_PLAN.md) and [`reference/datasheets/ASM2464PD.md`](reference/datasheets/ASM2464PD.md) before making electrical or mechanical changes.

## Authoritative controller pins

From the ASM2464PD datasheet reference currently used by this repo:

| Function | Ball/pin | Rev A net |
|---|---|---|
| UART TX | B21 | `ASM_UART_TX` |
| UART RX | A21 | `ASM_UART_RX` |
| SPI CS# | A2 | `ASM_SPI_CS_N` |
| SPI DO | A3 | `ASM_SPI_DO` |
| SPI DI | A4 | `ASM_SPI_DI` |
| SPI CLK | A5 | `ASM_SPI_CLK` |
| Reset | H1 | `ASM_RST_N` |

Treat voltage levels and reset-time drive state as unresolved until verified. Do not infer them solely from signal names.

## Reference-board work

Trace the Leaves232 B2 schematic/PCB and create:

- `reference/leaves232-b2/debug-net-map.md`
- `reference/leaves232-b2/debug-net-map.json`

For UART and U31 only, record:

- ASM pin/ball;
- B2 net name;
- connected component pin/pad;
- board coordinate;
- voltage rail;
- evidence source;
- confidence.

U31 is currently identified as `ZD25WQ16CEIGR`. Confirm its exact pinout and supply voltage from an authoritative flash datasheet before finalizing the connector.

## UART implementation

Route `ASM_UART_TX`, `ASM_UART_RX`, GND, and `VREF_SENSE` to the service connector.

Rules:

- TX/RX labels are target-relative.
- `VREF_SENSE` is measurement/reference only; do not use it to power the target.
- Determine the UART logic voltage before attaching any adapter.
- Do not commit a baud rate until runtime/firmware evidence proves it.
- Keep UART routing short and clear of USB4 differential pairs.

## Direct SPI flash implementation

Expose the flash bus required by a standard SPI programmer:

- `ASM_SPI_CS_N`
- `ASM_SPI_CLK`
- `ASM_SPI_DI` / programmer MOSI direction
- `ASM_SPI_DO` / programmer MISO direction
- GND
- flash-rail `VREF_SENSE`

The programmer must connect to the flash side of any isolation element.

### Mandatory bus-ownership proof

Before declaring in-circuit programming safe:

1. assert `ASM_RST_N`;
2. observe CS#, CLK, DI, and DO with a scope/logic analyzer;
3. prove whether the ASM2464PD releases the bus;
4. document the result.

If reset reliably tri-states the ASM flash interface, use reset as the normal programming gate.

If reset does **not** reliably release the bus, revise the PCB with deliberate isolation. Do not allow simultaneous programmer/controller drive and do not require functional firmware to surrender the bus.

## Rev A connector

Default provisional footprint: keyed 2x5, 1.27 mm pitch.

| Pin | Signal |
|---:|---|
| 1 | GND |
| 2 | VREF_SENSE |
| 3 | ASM_UART_TX |
| 4 | ASM_UART_RX |
| 5 | ASM_RST_N |
| 6 | ASM_SPI_CS_N |
| 7 | ASM_SPI_CLK |
| 8 | ASM_SPI_DI |
| 9 | ASM_SPI_DO |
| 10 | GND |

If mechanical constraints favor Tag-Connect/pogo, preserve the same logical interface.

## Flash-programming validation

The recovery workflow must prove all of the following on sacrificial/rework-safe hardware:

1. target flash voltage measured and documented;
2. controller held in the verified non-driving state;
3. programmer reads correct JEDEC ID;
4. complete flash backup can be read twice with matching hashes;
5. erase/program operation is range/size checked;
6. programmed contents are read back and hash-verified;
7. controller boots after programmer removal and reset release.

Never make the first write before a complete verified backup exists.

## UART validation

Demonstrate:

- boot-time output capture;
- stable RX/TX electrical levels;
- confirmed baud/framing recorded in `docs/uart-debug.md`;
- bidirectional communication if the firmware console accepts input.

## Mechanical implementation

Extend the CadQuery enclosure model with:

- exact debug connector body;
- mating cable/plug keepout;
- service aperture/cover;
- adequate strain relief/finger clearance.

Keep the service connector accessible while the enclosure is fully assembled. It must not compromise the ASM2464PD thermal interface, SSD fit, or USB-C cable clearance.

## Definition of done

Rev A is firmware-development-ready when we can, without opening the enclosure:

- connect a level-compatible UART adapter and capture ASM2464PD firmware debug output;
- hold/isolate the ASM safely;
- connect an SPI programmer;
- back up, erase, program, read back, and verify U31;
- release reset/isolation and boot the ASM normally.

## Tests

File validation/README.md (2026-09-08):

# Reproducible digital-twin validation

Install SDCC (tested 4.2.0) and Python dependencies from `simulation/requirements.txt`.
Run from the repository root:

```bash
python scripts/validate_twin.py
```

This verifies upstream hashes, builds the generic mcs51 firmware twice, runs flash/ownership tests and CPU boot/brick/recovery, executes all 18 fault rows, builds STEP/STL CAD, renders two reviews, checks the shared configuration hash, and writes `validation/twin-report.json` and compressed raw CPU traces.

`python scripts/validate_twin.py --require-rtl` returns nonzero while the mandatory second backend is unavailable. CPU repeatability is explicitly not CPU-versus-RTL differential equivalence.

Outputs:

- `mechanical/rev-a/build/assembly.step`, individual STEP/STL parts, assembled/exploded PNGs, dimensions and CAD validation.
- `simulation/asm2464/firmware/reference/build/`: IHX, raw binary, map, symbols, SHA-256, flash image, build manifest.
- `validation/twin-report.json`, `fault-matrix.json`, `cpu-recovery.jsonl.gz`.

The external NOR is a deterministic **command-level generic 16-Mbit profile**, with explicit assumed JEDEC and timings. Program/erase interruption deterministically affects a prefix proportional to elapsed model ticks. Illegal page-crossing and unaligned erases are rejected as a strict simulation policy. These are not claims of exact ZD25WQ16 silicon behavior. SPI events are normalized command transactions, not cycle-accurate pin waveforms. The controller MMIO ABI and flash-to-CODE loading convention come from the pinned upstream implementation; the silicon boot ROM is not reconstructed here.

The synthetic PCIe/NVMe endpoint remains the imported `HardwareState` implementation, owned by the board controller model. The minimal reference firmware exercises UART/SPI; PCIe/NVMe protocol boot is not validated by this milestone.

Physical component heights, connector selection, flash electrical parameters, reset behavior, full PCB ERC/DRC, USB4/PCIe signal integrity, thermal performance, assembly retention, and measured hardware recovery remain open gates. The renders use provisional fit envelopes. No fabrication readiness is claimed.

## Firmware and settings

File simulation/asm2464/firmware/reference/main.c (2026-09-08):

/* Project-owned boundary stimulus; compiled for the upstream mcs51 architecture. */
#include "profile.h"
__sfr __at(0xA8) IE;
__sfr __at(0x96) DPX;
#define REG(a) (*(volatile __xdata unsigned char *)(a))
static void putc(unsigned char c) { while (!(REG(0xC009)&0x20)) {} REG(0xC000)=c; }
static void puts(const __code char *s) { while (*s) putc(*s++); }
static void hex(unsigned char v) { const __code char *h="0123456789ABCDEF"; putc(h[v>>4]);putc(h[v&15]); }
static void command(unsigned char op,unsigned int count) {
    REG(0xC8A3)=count>>8;REG(0xC8A4)=count;REG(0xC8AA)=op;REG(0xC8A9)=1;
    while(REG(0xC8A9)&1) {}
}
void main(void) {
    unsigned char a,b,c,status;
    IE=0;DPX=0;REG(0xC007)=3;
    puts("ASM2464 REF FW\nBUILD=" BUILD_ID "\n");
    command(0x9F,3);a=REG(0x7000);b=REG(0x7001);c=REG(0x7002);
    puts("FLASH_ID=");hex(a);hex(b);hex(c);putc('\n');
    command(5,1);status=REG(0x7000);puts("FLASH_STATUS=");hex(status);putc('\n');
    if(a!=JEDEC0 || b!=JEDEC1 || c!=JEDEC2 || (status&1)) {puts("BOOT=FAIL\n");for(;;) {}}
    /* Read a marker in external flash, through the actual upstream MMIO ABI. */
    REG(0xC8AB)=0;REG(0xC8A2)=0;REG(0xC8A1)=0x80;command(3,4);
    if(REG(0x7000)!='R'||REG(0x7001)!='E'||REG(0x7002)!='F'||REG(0x7003)!='1') {puts("BOOT=FAIL\n");for(;;) {}}
    puts("BOOT=OK\n");for(;;) {}
}

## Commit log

2026-09-07 bootstrap ASM2464PD enclosure project
2026-09-07 docs: add UART and SPI recovery instructions
2026-09-07 simulation: define board-level digital twin scope
2026-09-07 mechanical: add parametric Rev A enclosure starter
2026-09-07 docs: require pinned ASM backends and board recovery simulation
2026-09-07 feat: couple Rev-A CAD with pinned ASM CPU and flash recovery simulation
    [assembly.step]
